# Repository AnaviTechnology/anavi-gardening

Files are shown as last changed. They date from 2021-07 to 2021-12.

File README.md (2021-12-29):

# ANAVI Gardening uHAT

iANAVI Gardening uHAT is a low-cost, open source Raspberry Pi add-on board that helps you develop smart solutions for monitoring and growing plants.

ANAVI Gardening uHAT supports multiple sensors for soil moisture, temperature, humidity, barometric pressure, and light. No soldering is required. Getting started is easy. You just plug it into a Raspberry Pi with your bare hands (no tools needed) and follow the steps from the user manual.

For more details please visit https://anavi.technology/ and https://www.crowdsupply.com/anavi-technology/anavi-gardening-uhat

## Features

* Slots for up to two capacitive soil moisture sensors
* Slot for waterproof temperature sensor
* Slots for up to two plug-and-play I2C sensors
* UART pins for serial communication
* GPIO pins for controlling irrigation systems and peripherals
* Green and red indication LEDs
* Microchip MCP3002 Analog-to-Digital Converter (ADC)
* Follows uHAT mechanical specification with a valid ID EEPROM
* Excellent software support, documentation, and open source examples

# Safety Guide

## English

### Warnings

* This product shall only be connected to a compatible Raspberry Pi.
      
### Instructions for safe use

* Do not expose this product to water or moisture, and do not place it on a conductive surface whilst in operation.
* Do not expose this product to heat from any source; it is designed for reliable operation at normal room temperatures.
* Take care while handling this product to avoid mechanical or electrical damage to the printed circuit board and connectors.
* Avoid handling this product while it is powered. Only handle by the edges to minimize the risk of electrostatic discharge damage.
      
## Deutsch

### Achtung

* Dieses Produkt darf nur mit einem kompatiblen Raspberry Pi verbunden werden.
      
### Anweisungen für die sichere Verwendung

* Setzen Sie dieses Produkt nicht Wasser oder Feuchtigkeit aus und stellen Sie es während des Betriebs nicht auf eine leitfähige Oberfläche.
* Setzen Sie dieses Produkt keiner Wärmequelle aus. Es ist für einen zuverlässigen Betrieb bei normalen Raumtemperaturen ausgelegt.
* Seien Sie vorsichtig beim Umgang mit diesem Produkt, um mechanische oder elektrische Schäden an der Leiterplatte und den Anschlüssen zu vermeiden.
* Vermeiden Sie die Handhabung dieses Produkts während der Stromversorgung. Produkt nur an den Rändern anfassen, um das Risiko von elektrostatischen Entladungsschäden zu minimieren.

# License

The project is released under the [Creative Commons Attribution-ShareAlike 4.0 International (CC BY-SA 4.0)](https://creativecommons.org/licenses/by-sa/4.0/).

Note: This is a human-readable summary of (and not a substitute for) the [license](https://creativecommons.org/licenses/by-sa/4.0/legalcode).

You are free to:

Share — copy and redistribute the material in any medium or format Adapt — remix, transform, and build upon the material for any purpose, even commercially. The licensor cannot revoke these freedoms as long as you follow the license terms. Under the following terms:

Attribution — You must give appropriate credit, provide a link to the license, and indicate if changes were made. You may do so in any reasonable manner, but not in any way that suggests the licensor endorses you or your use. ShareAlike — If you remix, transform, or build upon the material, you must distribute your contributions under the same license as the original. No additional restrictions — You may not apply legal terms or technological measures that legally restrict others from doing anything the license permits. Notices:

You do not have to comply with the license for elements of the material in the public domain or where your use is permitted by an applicable exception or limitation. No warranties are given. The license may not give you all of the permissions necessary for your intended use. For example, other rights such as publicity, privacy, or moral rights may limit how you use the material.

You will have to provide a link to the original creator of the project http://www.anavi.technology on any documentation or website.

Credit can be attributed through a link to the creator website: http://www.anavi.technology

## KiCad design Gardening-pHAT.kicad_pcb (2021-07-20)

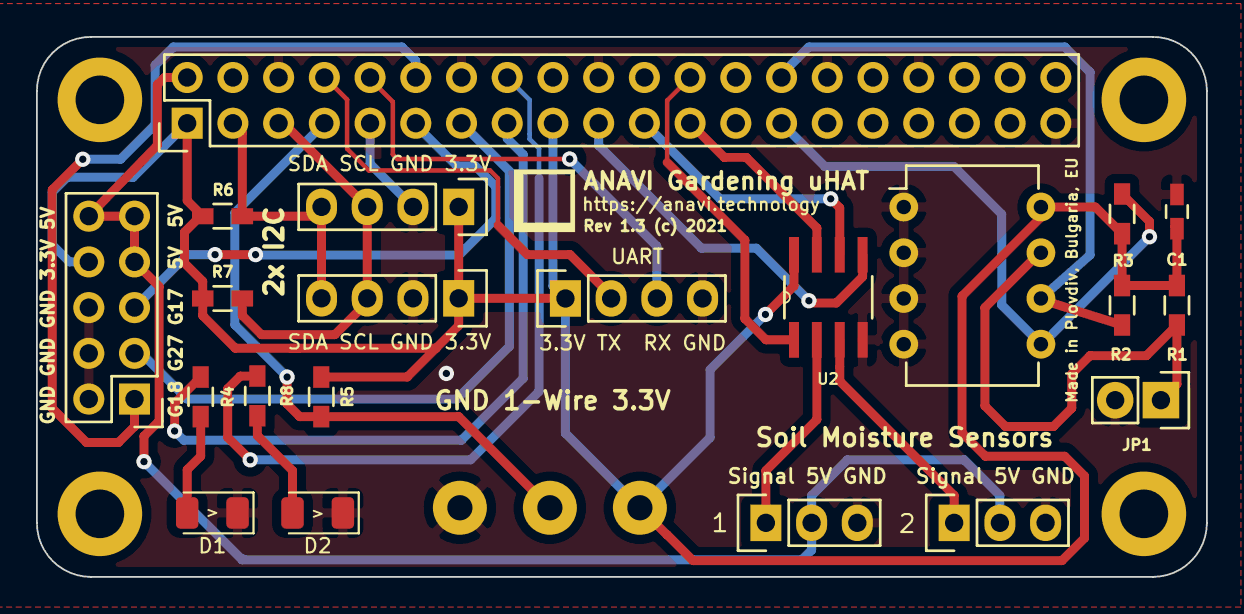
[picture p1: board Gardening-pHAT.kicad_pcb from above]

Board: 2 copper layers, 65.0 x 30.0 mm, 26 parts (0 on the bottom side), 24 nets.

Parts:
1, 2: CONN_01X03; Pin_Header_Straight_1x03
C1: 0.1; C_0603_HandSoldering
D1: KP-3216EC; LED_1206_3216Metric
D2: KP-3216SGC; LED_1206_3216Metric
JP1: JUMPER; Pin_Header_Straight_1x02
P1: CONN_01X03; KLEMA_1x3
P4: CONN_02X05; Pin_Header_Straight_2x05
R1: 1K; R_0603_HandSoldering
R2, R3, R5, R6, R7: 4.7K; R_0603_HandSoldering
R4, R8: 270R; R_0603_HandSoldering
RASP_CONN1: Raspberry_PI; Pin_Header_Straight_2x20
REF1, REF2, REF3, REF4: MountingHole_2.7mm_M2.5_DIN965_Pad
SENS1, SENS2: I2C_SENS_1; Pin_Header_Straight_1x04
U1: CAT24C32WI-GT3; DIP-8_W7.62mm
U2: MCP3002; SOIC127P600X175-8N
UART: CONN_01X04; Pin_Header_Straight_1x04

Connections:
+3V3: C1.1, P1.3, P4.8, R1.1, R2.1, R3.1, R5.1, R6.1, R7.1, RASP_CONN1.1, RASP_CONN1.17, SENS1.1, SENS2.1, U1.8, U2.8, UART.1
+5V: 1.2, 2.2, P4.7, P4.9, P4.10, RASP_CONN1.2, RASP_CONN1.4
/RXD: RASP_CONN1.10, UART.3
/TXD: RASP_CONN1.8, UART.2
GND: 1.3, 2.3, C1.2, D1.1, D2.1, JP1.2, P1.1, P4.2, P4.4, P4.6, RASP_CONN1.6, RASP_CONN1.9, RASP_CONN1.14, RASP_CONN1.20, RASP_CONN1.25, RASP_CONN1.30, RASP_CONN1.34, RASP_CONN1.39, SENS1.2, SENS2.2, U1.1, U1.2, U1.3, U1.4, U2.4, UART.4
unnamed: D1.2, R4.1
unnamed: D2.2, R8.1
unnamed: JP1.1, R1.2, U1.7
unnamed: P1.2, R5.2, RASP_CONN1.7
unnamed: 2.1, U2.3
unnamed: 1.1, U2.2
unnamed: P4.1, RASP_CONN1.12
unnamed: P4.3, RASP_CONN1.13
unnamed: P4.5, RASP_CONN1.11
unnamed: R2.2, RASP_CONN1.28, U1.6
unnamed: R3.2, RASP_CONN1.27, U1.5
unnamed: R4.2, RASP_CONN1.15
unnamed: R6.2, RASP_CONN1.3, SENS1.4, SENS2.4
unnamed: R7.2, RASP_CONN1.5, SENS1.3, SENS2.3
unnamed: R8.2, RASP_CONN1.16
unnamed: RASP_CONN1.19, U2.5
unnamed: RASP_CONN1.21, U2.6
unnamed: RASP_CONN1.23, U2.7
unnamed: RASP_CONN1.24, U2.1

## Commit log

2017-04-07 ANAVI Gardening pHAT
    Initial commit
    [Gardening-pHAT.kicad_pcb, Gardening-pHAT.sch]
2017-04-07 Remove one I2C slot and change labels
    Leave only two I2C slots to ensure that there is
    enough space for the labels. Fix wiring issues.
    [Gardening-pHAT.kicad_pcb, Gardening-pHAT.sch]
2017-04-07 Gardening-pHAT.kicad_pcb: Move labels
    [Gardening-pHAT.kicad_pcb]
2017-04-07 Gardening-pHAT.kicad_pcb: Replace labels
    Replace "Analog" with "Signal" and adjust the
    position of the labels.
    [Gardening-pHAT.kicad_pcb]
2017-04-09 Gardening-pHAT.sch: Hide text
    [Gardening-pHAT.sch]
2017-04-09 Gardening-pHAT.kicad_pcb: Change output directory
    [Gardening-pHAT.kicad_pcb]
2017-04-10 Fix routing
    [Gardening-pHAT.kicad_pcb, Gardening-pHAT.sch]
2017-04-10 Update fill zones
    [Gardening-pHAT.kicad_pcb]
2017-04-10 Update routing again
    [Gardening-pHAT.kicad_pcb, Gardening-pHAT.sch]
2017-04-10 Add junction between 5V pins on the header
    [Gardening-pHAT.kicad_pcb, Gardening-pHAT.sch]
2017-04-10 Gardening-pHAT.kicad_pcb: Hide UART connector text
    [Gardening-pHAT.kicad_pcb]
2017-04-21 Revision 1.1
    Revision 1.1 contains these improvements:
    * Fixed 1-wire connection for DS18B20 sensor
    * Swap GND and 3.3V for analog sensors
    * Update text labels
    [Gardening-pHAT.kicad_pcb, Gardening-pHAT.sch]
2017-04-24 Gardening-pHAT.kicad_pcb: rev 1.1
    [Gardening-pHAT.kicad_pcb]
2017-05-01 Control 3.3V to sensors through GPIO
    Connect the 3.3V of the soil moisture sensors
    to GPIO5 and GPIO6 of Raspberry Pi. This way
    the sensors will be enabled only during
    measurement and their life will be significantly
    increased.
    [Gardening-pHAT.kicad_pcb, Gardening-pHAT.sch]
2021-05-07 Gardening-pHAT.*: Remap symbols
    Remap symbols for newer KiCad version.
    [Gardening-pHAT.sch]
2021-05-11 Gardening-pHAT: Update tracks
    Update tracks and labels.
    [Gardening-pHAT.kicad_pcb, Gardening-pHAT.sch]
2021-07-20 Add fabrication labels for assemly
    Create additional labels on the fabrication layer to help with
    the SMT assembly of the PCB.
    [Gardening-pHAT.kicad_pcb, Gardening-pHAT.sch]

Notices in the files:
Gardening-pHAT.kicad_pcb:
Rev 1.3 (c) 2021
